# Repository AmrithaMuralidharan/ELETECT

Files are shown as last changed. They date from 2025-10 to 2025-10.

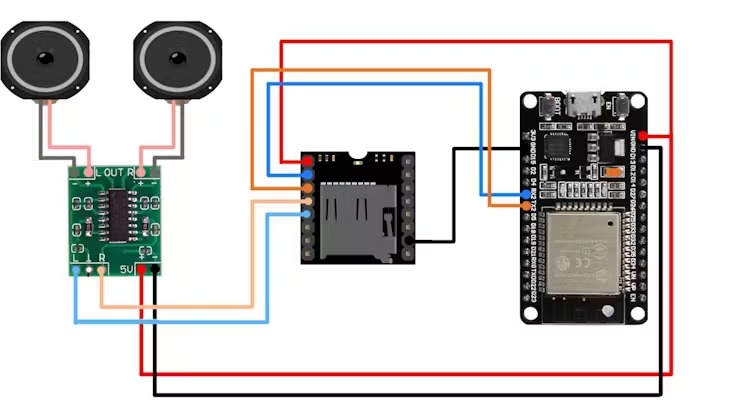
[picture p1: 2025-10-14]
ELETECT 2.O/ELETECT RAZOR/SCHEMATICS AND PCB/eletect.jpg

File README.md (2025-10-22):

# 🐘 EleTect 2.0 – Intelligent Ecosystem for Human–Wildlife Coexistence


[]()
[]()

---

### 🌍 Overview

*EleTect* is a modular, AI-powered ecosystem of devices designed to promote *human–wildlife coexistence*, prevent conflicts, and protect both nature and communities.  
Built using *TinyML, **LoRa, and **bio-inspired design principles, EleTect redefines conservation technology through **low-power, scalable, and sustainable innovation*.

This repository covers the complete *EleTect 2.0 system* and its modular extensions — forming a connected network of intelligent devices that monitor, detect, deter, and communicate in real-time.

---

Field Survey, Official Approval & Real-World Trials
To ensure EleTect was not just a lab prototype but a real-world conservation tool, our team carried out an extensive ground survey and obtained official permission for field testing from the Divisional Forest Officer (DFO) of Kothamangalam, Mr. Varun Dalia, IFS, and Forest Range Officer, Mr. Jaleel.


After the survey phase, we formally presented EleTect to the DFO Office, Kothamangalam, and Forest Range Office to discuss its technical operation, safety, and ecological compatibility.



I’ve started a discussion on WILDLABS for EleTect 2.0: AI-Powered Ecosystem for Human–Wildlife Coexistence — you can check it out here:
🔗 WILDLABS Discussion – https://wildlabs.net/discussion/eletect-20-ai-powered-ecosystem-human-wildlife-coexistence

eletect abhi

Please feel free to drop your insights, suggestions, or deployment experiences — especially if you’ve worked in conservation tech, forest environments, LoRa mesh networks, or wildlife deterrents. I’d love to learn from your field knowledge and improve EleTect’s design, robustness, and real-world usability together with the community.

## 🧩 Ecosystem Lineup

### *1️⃣ EleTect 2.0 – The Core System*
> The central AI-powered unit for *human–elephant conflict mitigation*.

- Dual *vision + acoustic AI* detection for real-time elephant identification.  
- *Bio-inspired deterrent* using honeybee swarm sounds.  
- Detects *illegal human activities* (gunshots, chainsaws, vehicles).  
- *Solar-powered, **LoRa-enabled, and capable of **local data logging* (SD + RTC).  
- Acts as the *hub* of the entire EleTect ecosystem.  

📘 Detailed Documentation: [EleTect 2.0 Hackster Project](https://www.hackster.io/abhinav123krish/eletect-2-0-76abc2)

---

### *2️⃣ EleTect Razor – Modular Boar Deterrent*
> A plug-and-play module that attaches to EleTect 2.0.

- High-intensity *strobe lights* and *ultrasonic deterrence*.  
- EEPROM-based auto-recognition for instant configuration.  
- Designed to adapt EleTect 2.0 for wild boar management.  

---

### *3️⃣ EleTect 1.5 – Smarter Roads, Safer Journeys*
> Intelligent wildlife signage for road safety near forest areas.

- Deployed along *elephant corridors (Aana Thaara)* using local knowledge for placement.  
- Communicates with detection nodes via *LoRa*.  
- *Solar-powered* system that warns vehicles in real-time.  
- Can be extended to detect *other large animals* in crossings.  

📘 Detailed Documentation: [EleTect 1.5 Hackster Project](https://www.hackster.io/abhinav123krish/eletect-1-5-smarter-warnings-safer-journeys-1597d3)

---

### *4️⃣ EleTect Mini – Compact Multi-Animal Deterrent*
> A lightweight, portable solution for farms and households.

- Built using *XIAO ESP32S3 + TinyML*.  
- *Rotary mode selector* for species-specific deterrence (birds, dogs, monkeys, squirrels, etc.).  
- Dual charging: *USB Type-C + Solar*.  
- Features dual “eye” strobes and an intelligent speaker for deterrence.  

---

### *5️⃣ EleTect Echo – Acoustic Surveillance Node*
> The forest’s “ears” — monitoring illegal activity 24/7.

- Detects *gunshots, logging, vehicle movement*, and unusual sounds.  
- Logs acoustic data to SD with timestamps (RTC-based).  
- Transmits alerts via *LoRa MeshStatic* to ranger units.  

---

### *6️⃣ EleTect Ember – Early Wildfire Detection*
> A stackable add-on for Echo, creating a complete forest monitoring suite.

- Detects *smoke, flame, temperature, and **gas anomalies*.  
- Early fire alerts sent to connected *Echo nodes* and *EleTect Link*.  
- Modular “Lego-style” design — Echo and Ember interlock seamlessly.  

---

### *7️⃣ EleTect Link – Ranger Communication Device*
> Handheld, smart, and always connected.

- Connects to EleTect 2.0, Echo, and Ember via *LoRa MeshStatic*.  
- Displays real-time alerts on an *OLED/e-paper screen*.  
- Supports *SOS signaling, **vibration, and **buzzer alerts*.  
- Works fully *offline*, enabling communication deep inside forests.  

---

## 🧠 Innovation Highlights

- ✅ *TinyML + IoT Fusion* – Real-time detection on low-power devices.  
- 🌿 *Bio-inspired Design* – Honeybee deterrence derived from natural elephant behavior.  
- ☀ *Solar-Powered Systems* – Fully off-grid and sustainable.  
- 🔗 *Modular Architecture* – Attach, adapt, and scale easily.  
- 🛰 *LoRa + Mesh Communication* – Long-range, internet-independent alerts.  
- 🧩 *Cross-Compatible Modules* – All devices interconnect as a unified network.  

---

### 🔗 Refer to the Projects documentation on huckster.io
- 🐘 *EleTect 1.0 – Original Prototype:* [Mitigating Human–Elephant Conflict with TinyML](https://www.hackster.io/517317/eletect-mitigating-human-elephant-conflict-with-tinyml-31a66d)  
- 🚦 *EleTect 1.5 – Smarter Warnings, Safer Journeys:* [Smart Wildlife Signage](https://www.hackster.io/abhinav123krish/eletect-1-5-smarter-warnings-safer-journeys-1597d3)  
- 🧠 *EleTect 2.0 – Advanced Ecosystem:* [AI + IoT for Conservation](https://www.hackster.io/abhinav123krish/eletect-2-0-76abc2)

---

## 🚀 Getting Started

### *1️⃣ Clone this repository*
```bash
git clone https://github.com/abhinavkrish/EleTect-2.0.git
cd EleTect-2.0

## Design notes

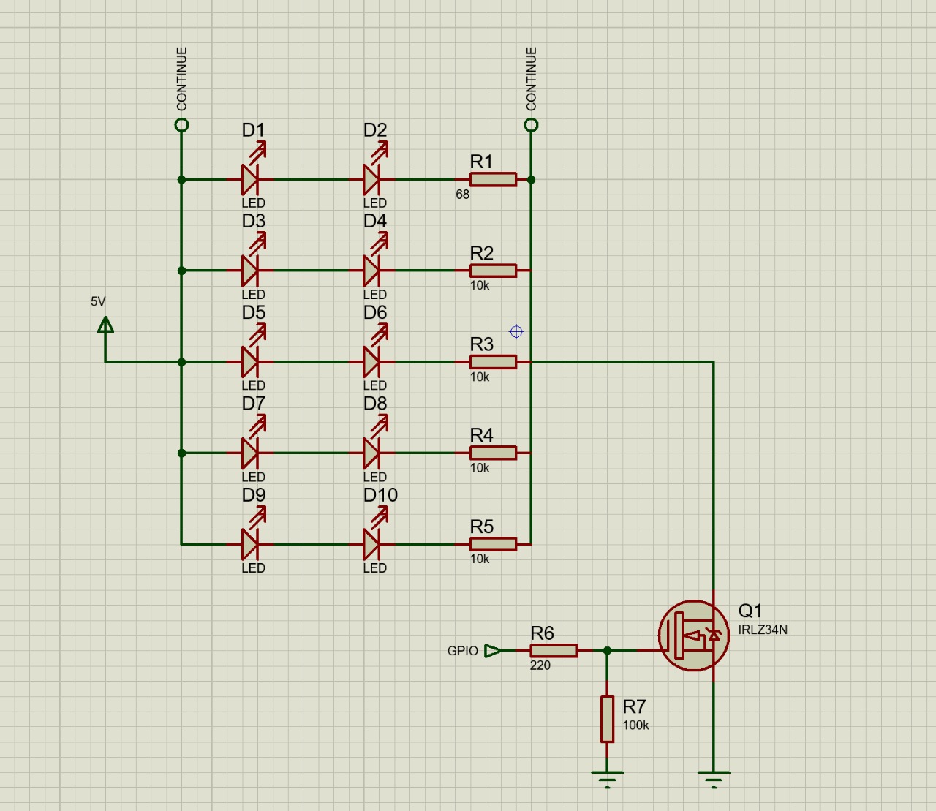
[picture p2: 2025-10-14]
ELETECT 2.O/ELETECT RAZOR/SCHEMATICS AND PCB/eletect (2).jpg

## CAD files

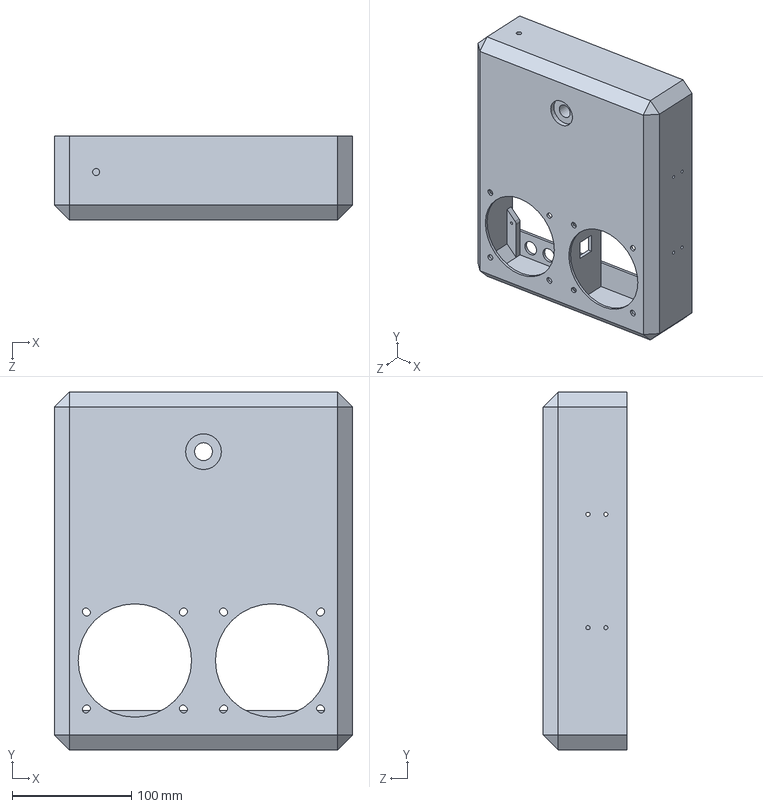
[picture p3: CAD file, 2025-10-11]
ELETECT 2.O/ELETECT 2.O/CAD/Eletect/Main Casing.SLDPRT
250.0 x 300.0 x 70.0 mm

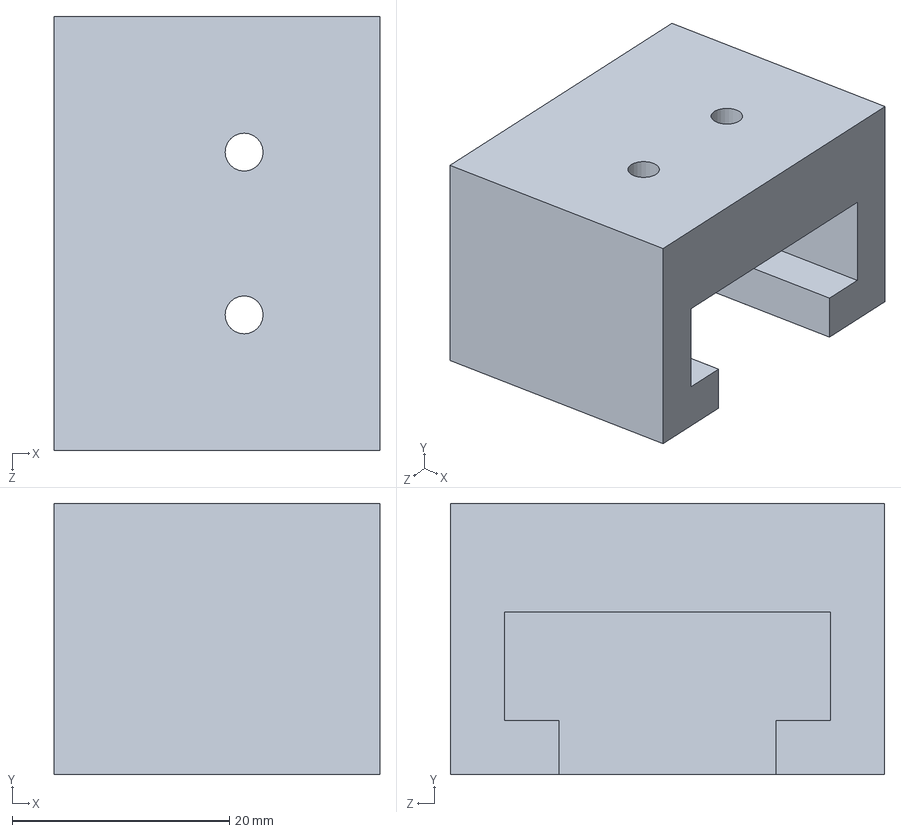
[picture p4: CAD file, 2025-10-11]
ELETECT 2.O/ELETECT 2.O/CAD/Eletect/UCM2.SLDPRT
30.0 x 25.0 x 40.0 mm

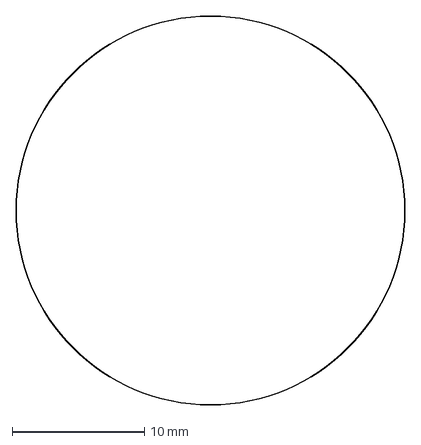
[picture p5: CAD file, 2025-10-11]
ELETECT 2.O/ELETECT 2.O/CAD/Sketch1 .dxf
29.4 x 29.4 mm

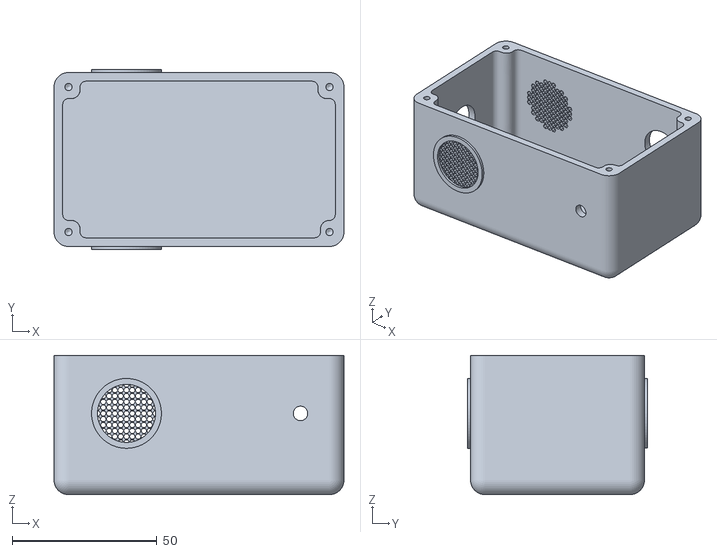
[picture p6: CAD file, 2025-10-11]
ELETECT 2.O/ELETECT ECHO/CAD/BOX1NEW_ v1.stl
100.0 x 62.0 x 48.0

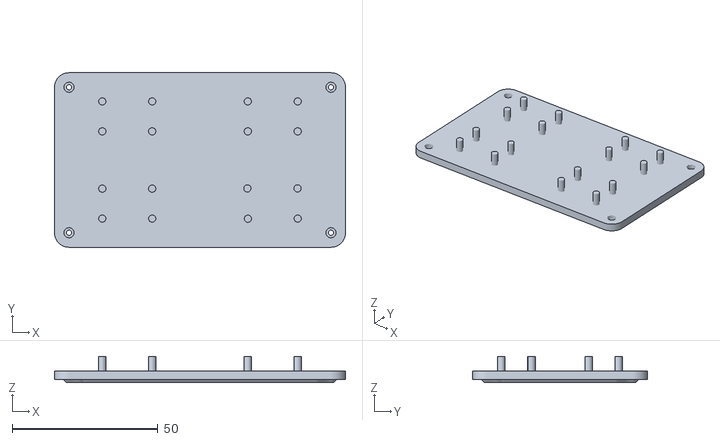
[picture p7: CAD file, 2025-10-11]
ELETECT 2.O/ELETECT EMBER/CAD/lid2NEW_.stl
100.0 x 60.0 x 9.00

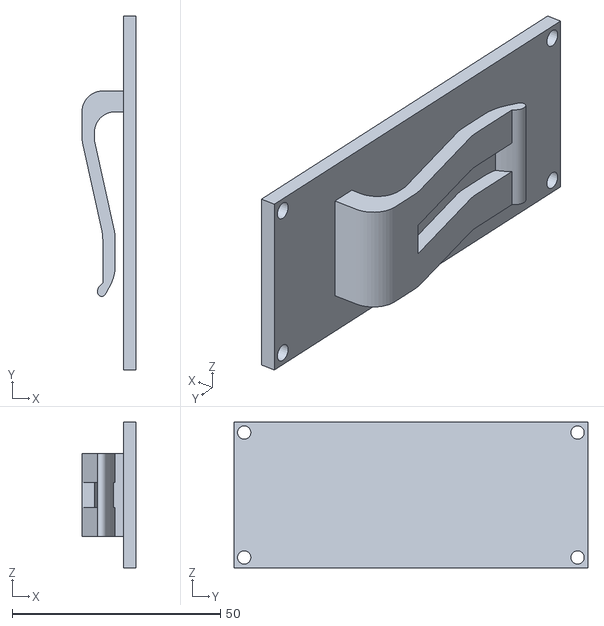
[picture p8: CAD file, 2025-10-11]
ELETECT 2.O/ELETECT LINK/CAD/rangerbp.stl
13.0 x 85.0 x 35.0

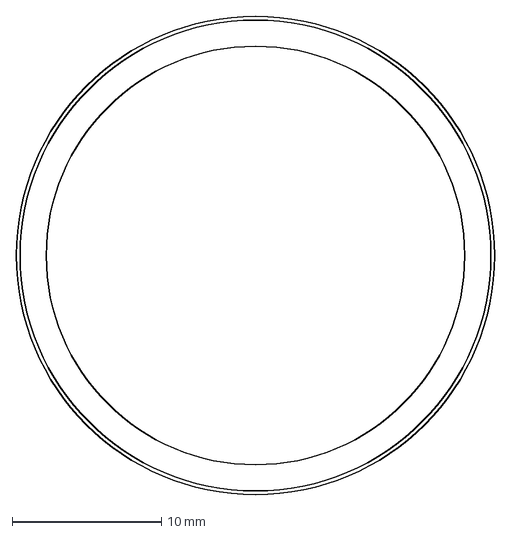
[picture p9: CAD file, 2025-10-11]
ELETECT 2.O/ELETECT MINI/CAD/Sketch2.dxf
32.0 x 32.0 mm

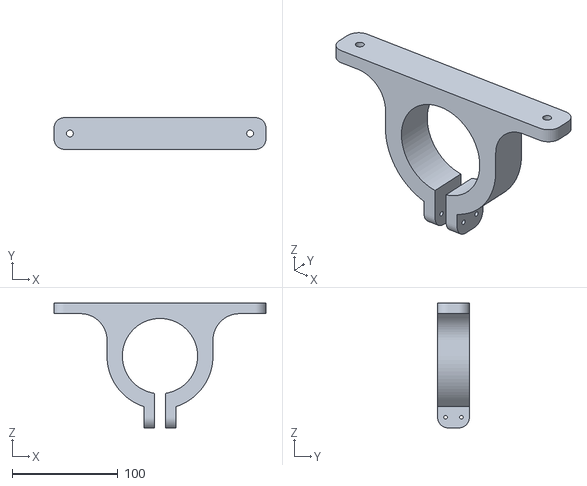
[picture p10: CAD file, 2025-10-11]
ELETECT 2.O/ELETECT RAZOR/CAD/clamping.stl
200.0 x 30.0 x 117.8

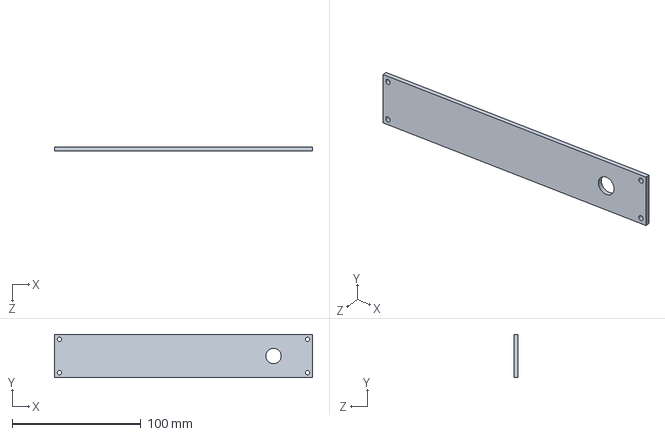
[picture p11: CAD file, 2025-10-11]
ELETECT 2.O/ELETECT RAZOR/CAD/Eletect/us bp.SLDPRT
200.6 x 33.6 x 3.00 mm

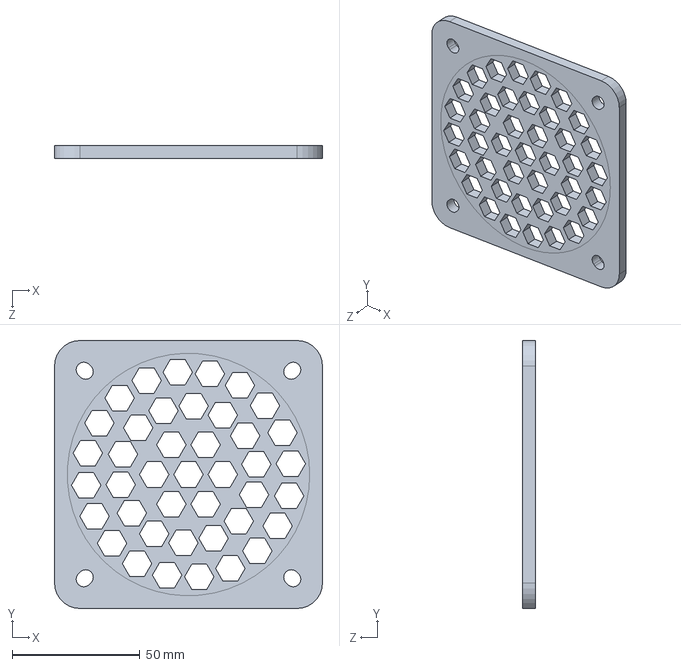
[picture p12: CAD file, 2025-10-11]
ELETECT 2.O/ELETECT 2.O/CAD/Eletect/speaker grill.SLDPRT
105.0 x 105.0 x 5.00 mm

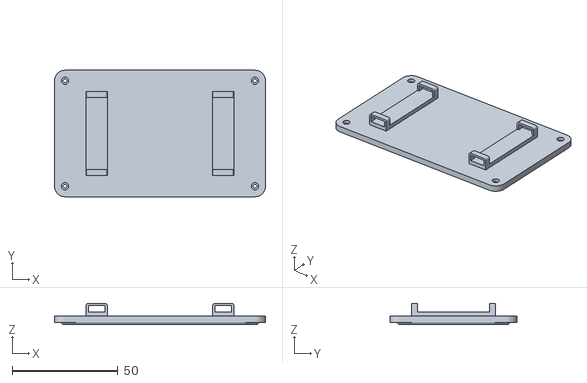
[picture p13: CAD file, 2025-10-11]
ELETECT 2.O/ELETECT ECHO/CAD/lid.stl
100.0 x 60.0 x 10.0

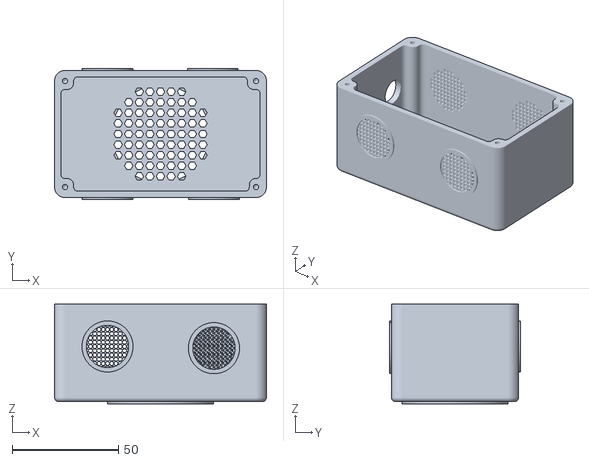
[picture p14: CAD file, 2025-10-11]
ELETECT 2.O/ELETECT EMBER/CAD/box2NEW_ v1.stl
100.0 x 62.0 x 47.1

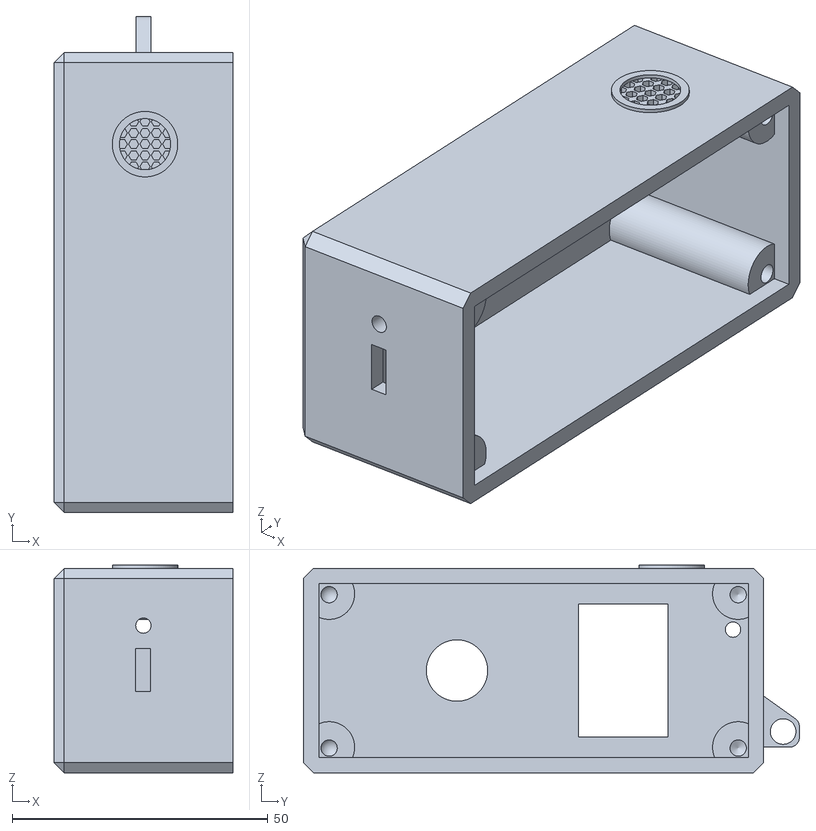
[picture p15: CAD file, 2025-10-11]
ELETECT 2.O/ELETECT LINK/CAD/ranger1.stl
35.0 x 97.0 x 40.6

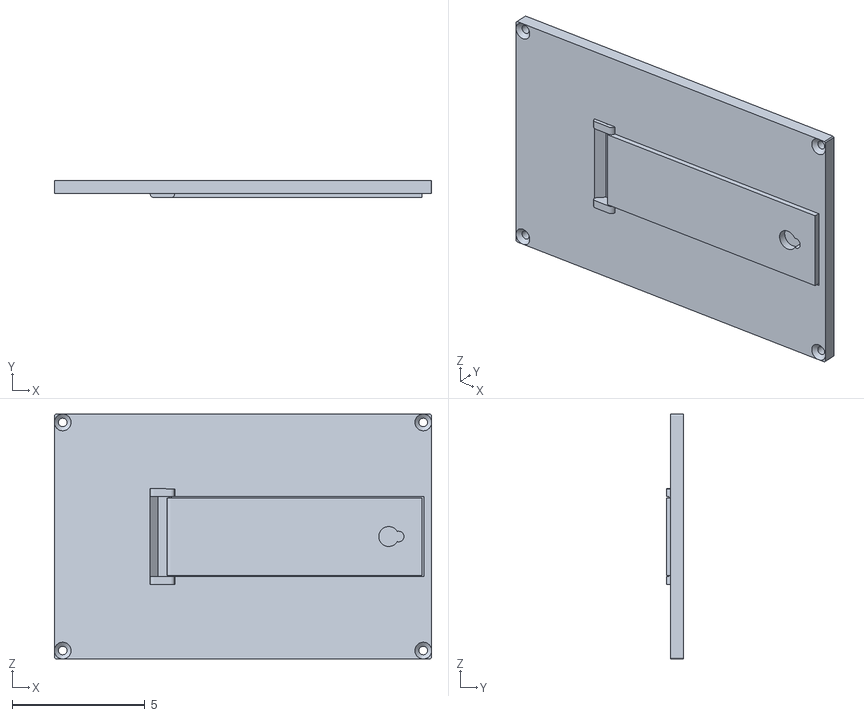
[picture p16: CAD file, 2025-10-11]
ELETECT 2.O/ELETECT MINI/CAD/mini bp.stl
14.2 x 0.65 x 9.22

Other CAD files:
ELETECT 2.O/ELETECT 2.O/CAD/Eletect/Eletect.SLDASM
ELETECT 2.O/ELETECT RAZOR/CAD/Eletect/Eletect.SLDASM
ELETECT 2.O/ELETECT 2.O/CAD/Eletect/1.SLDPRT
ELETECT 2.O/ELETECT 2.O/CAD/Eletect/AC.SLDPRT
ELETECT 2.O/ELETECT 2.O/CAD/Eletect/AL.SLDPRT
ELETECT 2.O/ELETECT 2.O/CAD/Eletect/Back Panel.SLDPRT
ELETECT 2.O/ELETECT 2.O/CAD/Eletect/LM1.SLDPRT
ELETECT 2.O/ELETECT 2.O/CAD/Eletect/LM2.SLDPRT
ELETECT 2.O/ELETECT 2.O/CAD/Eletect/Light casing.SLDPRT
ELETECT 2.O/ELETECT 2.O/CAD/Eletect/UCM1.SLDPRT
ELETECT 2.O/ELETECT 2.O/CAD/Eletect/USC.SLDPRT
ELETECT 2.O/ELETECT 2.O/CAD/Eletect/clamping.SLDPRT
ELETECT 2.O/ELETECT 2.O/CAD/Eletect/light back panel.SLDPRT
ELETECT 2.O/ELETECT 2.O/CAD/Sketch1.dxf
ELETECT 2.O/ELETECT MINI/CAD/Sketch3.dxf
ELETECT 2.O/ELETECT MINI/CAD/mini case.stl
ELETECT 2.O/ELETECT RAZOR/CAD/Eletect/1.SLDPRT
ELETECT 2.O/ELETECT RAZOR/CAD/Eletect/AC.SLDPRT
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

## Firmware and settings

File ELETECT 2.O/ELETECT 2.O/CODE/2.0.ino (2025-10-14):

/*  final version
   - Grove Vision AI V2 (UART)
   - Edge Impulse audio inference (XIAO ESP32S3)
   - DFRobotDFPlayerMini playback (random files: /01 honeybee, /02 boar)
   - SD logging: /log.csv (detailed) and /events.csv (timestamp,event,locality)
   - RTC DS3231 for timestamps
   - Meshtastic UART (Serial2) send
   - EEPROM probe at 0x50 -> if present, switch to BOAR mode (razor add-on attached)
   - BOAR deterrent: randomized strobes + ultrasonic PWM
*/

/* === LIBRARIES === */
#include <Wire.h>
#include <SPI.h>
#include <SD.h>
#include <LoRa.h>
#include <RTClib.h>

#include <Seeed_Arduino_SSCMA.h>     // Grove Vision AI V2 (UART API)
#include "DFRobotDFPlayerMini.h"    // DFPlayer library
#include <SoftwareSerial.h>

#define EIDSP_QUANTIZE_FILTERBANK   0
#include <EleTect_inferencing.h>    // Edge Impulse inferencing glue
#include <I2S.h>

/* === HARDWARE / PIN CONFIG - EDIT THESE TO MATCH YOUR WIRING === */

// DFPlayer SoftwareSerial pins (example)
#define DFPLAYER_SOFT_RX 10 // connect to DFPlayer TX
#define DFPLAYER_SOFT_TX 11 // connect to DFPlayer RX

// SD card for logging
#define SD_CS_PIN 5       // change to match wiring

// LoRa pins (example)
#define LORA_SS    18
#define LORA_RST   14
#define LORA_DIO0  26
#define LORA_FREQ  915E6  // change to your region: 433E6 / 868E6 / 915E6

// I2S pins for audio capture (change if your mic uses different pins)
#define I2S_BCK_PIN  -1
#define I2S_WS_PIN   42
#define I2S_DIN_PIN  41
#define I2S_DOUT_PIN -1

// Meshtastic UART pins (change to your wiring)
const int MESHTASTIC_RX_PIN = 16; // XIAO RX (connect to Wio TX)
const int MESHTASTIC_TX_PIN = 17; // XIAO TX (connect to Wio RX)
const unsigned long MESHTASTIC_BAUD = 38400; // must match Serial Module baud

/* === BOAR-DETERRER / EEPROM ADD-ON PINS & SETTINGS ===
   NOTE: change pins below if they conflict with your wiring.
   I chose default pins that minimize collision with the other defaults above.
*/
#define EEPROM_I2C_ADDR 0x50   // typical 24LC02 address
#define EEPROM_CHECK_INTERVAL 5000UL // ms: re-check EEPROM presence

// Strobe/ultrasonic pins - change if these collide with other devices
const int STROBE1_PIN = 32;   // MOSFET gate for strobe 1
const int STROBE2_PIN = 33;   // MOSFET gate for strobe 2
const int ULTRA_PIN   = 25;   // PWM pin for ultrasonic tweeter

// ultrasonic PWM settings (ledc)
const int ULTRA_FREQ = 25000; // 25 kHz (tweak for your tweeter)
const int ULTRA_CHANNEL = 1;  // ledc channel (use a free channel)
const int ULTRA_RESOLUTION = 8; // 8-bit duty (0..255)
const int ULTRA_MAX_DUTY = 200; // maximum duty (tune to hardware)

// deterrent timing & randomness
const unsigned long BOAR_DETERR_COOLDOWN_MS = 15000UL;   // cooldown between deterrent triggers
const unsigned long DETERR_MIN_MS = 5000UL;  // min duration of deterrent (ms)
const unsigned long DETERR_MAX_MS = 12000UL; // max duration of deterrent (ms)

/* === GENERAL DEFINITIONS / FILES === */
#define LOG_CSV    "/log.csv"
#define EVENTS_CSV "/events.csv"

#ifdef ESP32
  #include <HardwareSerial.h>
  HardwareSerial atSerial(0); // Grove Vision UART (keeps your original approach)
#else
  #define atSerial Serial1
#endif

SSCMA AI;                         // Vision AI object
SoftwareSerial mySoftSerial(DFPLAYER_SOFT_RX, DFPLAYER_SOFT_TX);
DFRobotDFPlayerMini myDFPlayer;

RTC_DS3231 rtc;
File logFile;

/* DFPlayer folders / defaults */
const uint8_t ELEPHANT_FOLDER = 1; // honeybee sounds in /01/
const uint8_t BOAR_FOLDER      = 2; // crackers/predator in /02/
const uint8_t NUM_FILES_PER_FOLDER = 20; // fallback

const int SCORE_THRESHOLD = 80;   // vision score threshold (0..100)
const unsigned long PLAYBACK_COOLDOWN_MS = 10000UL; // cool-down for audio/vision playback
unsigned long lastElephantAt = 0;
unsigned long lastBoarAt     = 0;

/* EDGE IMPULSE AUDIO BUFFERS (adapted) */
typedef struct {
    int16_t *buffer;
    uint8_t buf_ready;
    uint32_t buf_count;
    uint32_t n_samples;
} inference_t;

static inference_t inference;
static const uint32_t sample_buffer_size = 2048;
static signed short sampleBuffer[sample_buffer_size];
static bool debug_nn = false;
static bool record_status = true;

const float CONFIDENCE_THRESHOLD = 0.60f; // audio classification threshold

/* STATE FLAGS */
bool sd_ok = false;
bool rtc_ok = false;
bool meshtastic_ok = false;
bool eepromPresent = false;
unsigned long lastEEPROMCheck = 0;
unsigned long lastBoarDeterrentAt = 0;

/* FORWARD DECLARATIONS */
String detectVision();
String detectAudio();
void playRandomFromFolder(uint8_t folderNumber);
void logEvent(DateTime ts, const String &visionLabel, const String &audioLabel, const String &action, const String &soundFile, const String &loraStatus);
bool sendLoRa(const String &visionLabel, const String &audioLabel, const String &action);
String timestampNow();
void appendEvent(const String &timestamp, const String &event);
void meshtastic_begin();
void sendMeshtastic(const char *eventName);

/* BOAR deterrent helpers */
bool probeEEPROM();                 // probe I2C EEPROM presence
void updateModeFromEEPROM();        // set mode based on probe
void runBoarDeterrent();            // start randomized deterrent
void runStrobePattern(int onMs, int offMs, int repeats, bool alternate);
void runRandomSingleStrobe(int count, int minMs, int maxMs);

/* === AUDIO CAPTURE HELPERS (Edge Impulse) === */
static void audio_inference_callback(uint32_t n_bytes)
{
    for(int i = 0; i < (n_bytes >> 1); i++) {
        inference.buffer[inference.buf_count++] = sampleBuffer[i];
        if(inference.buf_count >= inference.n_samples) {
            inference.buf_count = 0;
            inference.buf_ready = 1;
        }
    }
}

static void capture_samples(void* arg) {
  const int32_t i2s_bytes_to_read = (uint32_t)arg;
  size_t bytes_read = i2s_bytes_to_read;
  while (record_status) {
    esp_i2s::i2s_read(esp_i2s::I2S_NUM_0, (void*)sampleBuffer, i2s_bytes_to_read, &bytes_read, 100);
    if (bytes_read <= 0) {
      ei_printf("Error in I2S read : %d", bytes_read);
    } else {
      if (bytes_read < i2s_bytes_to_read) {
        ei_printf("Partial I2S read");
      }
      for (int x = 0; x < i2s_bytes_to_read/2; x++) {
        sampleBuffer[x] = (int16_t)(sampleBuffer[x]) * 8;
      }
      if (record_status) {
        audio_inference_callback(i2s_bytes_to_read);
      } else {
        break;
      }
    }
  }
  vTaskDelete(NULL);
}

static bool microphone_inference_start(uint32_t n_samples)
{
    inference.buffer = (int16_t *)malloc(n_samples * sizeof(int16_t));
    if(inference.buffer == NULL) {
        return false;
    }
    inference.buf_count  = 0;
    inference.n_samples  = n_samples;
    inference.buf_ready  = 0;
    ei_sleep(100);
    record_status = true;
    xTaskCreate(capture_samples, "CaptureSamples", 1024 * 32, (void*)sample_buffer_size, 10, NULL);
    return true;
}

static bool microphone_inference_record(void)
{
    while (inference.buf_ready == 0) {
        delay(10);
    }
    inference.buf_ready = 0;
    return true;
}

static int microphone_audio_signal_get_data(size_t offset, size_t length, float *out_ptr)
{
    numpy::int16_to_float(&inference.buffer[offset], out_ptr, length);
    return 0;
}

static void microphone_inference_end(void)
{
    if (inference.buffer) {
        ei_free(inference.buffer);
        inference.buffer = NULL;
    }
}

/* === VISION (UART-based) === */
String detectVision() {
  if (!AI.invoke(1, false, false)) {
    auto &boxes = AI.boxes();
    for (int i = 0; i < boxes.size(); i++) {
      int score = boxes[i].score;
      if (score > SCORE_THRESHOLD) {
        String label = boxes[i].label;
        label.toLowerCase();
        label.trim();
        if (label == "elephant" || label.indexOf("eleph") >= 0) {
          Serial.printf("{ \"elephant_detected\": %d }\n", score);
          return "elephant";
        } else if (label == "boar" || label == "wildboar" || label.indexOf("boar") >= 0) {
          Serial.printf("{ \"boar_detected\": %d }\n", score);
          return "wildboar";
        } else {
          Serial.printf("{ \"%s_detected\": %d }\n", label.c_str(), score);
          return label;
        }
      }
    }
  }
  return "none";
}

/* === AUDIO DETECTION WRAPPER === */
String detectAudio() {
  if (!microphone_inference_record()) {
    ei_printf("ERR: Failed to record audio...\n");
    return "none";
  }
  signal_t signal;
  signal.total_length = EI_CLASSIFIER_RAW_SAMPLE_COUNT;
  signal.get_data = &microphone_audio_signal_get_data;
  ei_impulse_result_t result = { 0 };
  EI_IMPULSE_ERROR r = run_classifier(&signal, &result, debug_nn);
  if (r != EI_IMPULSE_OK) {
    ei_printf("ERR: Failed to run classifier (%d)\n", r);
    return "none";
  }
  int pred_index = -1;
  float pred_value = 0.0f;
  for (size_t ix = 0; ix < EI_CLASSIFIER_LABEL_COUNT; ix++) {
    if (result.classification[ix].value > pred_value) {
      pred_index = ix;
      pred_value = result.classification[ix].value;
    }
  }
  if (pred_index < 0 || pred_value < CONFIDENCE_THRESHOLD) {
    ei_printf("No confident detection (best: %d = %f)\n", pred_index, pred_value);
    return "none";
  }
  const char *label = result.classification[pred_index].label;
  ei_printf("DETECTED (audio): %s (%.2f)\n", label, pred_value);
  return String(label);
}

/* === DFPlayer helper === */
void playRandomFromFolder(uint8_t folderNumber) {
  int fileCount = myDFPlayer.readFileCountsInFolder(folderNumber);
  if (fileCount <= 0) fileCount = NUM_FILES_PER_FOLDER;
  int fileIndex = random(1, fileCount + 1);
  int vol = 28 + (random(0, 3)); // 28-30
  if (vol > 30) vol = 30;
  myDFPlayer.volume(vol);
  Serial.print("Playing folder ");
  Serial.print(folderNumber);
  Serial.print(" file ");
  Serial.print(fileIndex);
  Serial.print(" at volume ");
  Serial.println(vol);
  myDFPlayer.playFolder(folderNumber, fileIndex);
}

/* === DETAILED LOGGING === */
void logEvent(DateTime ts, const String &visionLabel, const String &audioLabel, const String &action, const String &soundFile, const String &loraStatus) {
  if (!sd_ok) {
    Serial.println("SD not available, skipping detailed log");
    return;
  }
  File f = SD.open(LOG_CSV, FILE_APPEND);
  if (!f) {
    Serial.println("Failed to open " LOG_CSV);
    return;
  }
  char timestr[32];
  snprintf(timestr, sizeof(timestr), "%04d-%02d-%02d %02d:%02d:%02d",
           ts.year(), ts.month(), ts.day(), ts.hour(), ts.minute(), ts.second());
  String line = String(timestr) + "," + visionLabel + "," + audioLabel + "," + action + "," + soundFile + "," + loraStatus + "\n";
  f.print(line);
  f.close();
  Serial.println("Logged (detailed): " + line);
}

/* === EVENTS CSV (timestamp,event,locality) === */
String timestampNow() {
  if (rtc_ok) {
    DateTime now = rtc.now();
    char buf[32];
    snprintf(buf, sizeof(buf), "%04d-%02d-%02d %02d:%02d:%02d",
             now.year(), now.month(), now.day(),
             now.hour(), now.minute(), now.second());
    return String(buf);
  } else {
    unsigned long s = millis() / 1000;
    char buf[32];
    snprintf(buf, sizeof(buf), "uptime_%lus", s);
    return String(buf);
  }
}

void appendEvent(const String &timestamp, const String &event) {
  if (!sd_ok) {
    Serial.println("SD not available, skipping events.csv append");
    return;
  }
  File f = SD.open(EVENTS_CSV, FILE_WRITE); // append mode
  if (!f) {
    Serial.println("Error opening " EVENTS_CSV " for append");
    return;
  }
  String safeEvent = event;
  safeEvent.replace(",", " ");
  f.print(timestamp);
  f.print(",");
  f.print("\"");
  f.print(safeEvent);
  f.print("\"");
  f.print(",");
  f.println("kothamangalam");
  f.close();
  Serial.print("Logged (event): ");
  Serial.print(timestamp);
  Serial.print(" , ");
  Serial.println(safeEvent);
}

/* === LoRa send === */
bool sendLoRa(const String &visionLabel, const String &audioLabel, const String &action) {
  String payload = String("{\"t\":\"") + String(millis()) + String("\",\"v\":\"") + visionLabel + String("\",\"a\":\"") + audioLabel + String("\",\"act\":\"") + action + String("\"}");
  LoRa.beginPacket();
  LoRa.print(payload);
  LoRa.endPacket();
  Serial.println("LoRa sent: " + payload);
  return true;
}

/* === Meshtastic helpers === */
void meshtastic_begin() {
  Serial2.begin(MESHTASTIC_BAUD, SERIAL_8N1, MESHTASTIC_RX_PIN, MESHTASTIC_TX_PIN);
  delay(50);
  meshtastic_ok = true;
  Serial.println("Meshtastic UART (Serial2) initialized.");
}

void sendMeshtastic(const char *eventName) {
  if (!meshtastic_ok) {
    Serial.println("Meshtastic not initialized, skip sending");
    return;
  }
  String ts = timestampNow();
  String payload = String("{\"loc\":\"kothamangalam\",\"time\":\"") + ts + String("\",\"event\":\"") + eventName + String("\"}");
  Serial.print("-> mesh: ");
  Serial.println(payload);
  Serial2.println(payload);
}

/* === EEPROM / BOAR DETERRER === */
bool probeEEPROM() {
  Wire.beginTransmission(EEPROM_I2C_ADDR);
  byte err = Wire.endTransmission();
  if (err == 0) {
    Serial.println("EEPROM detected on I2C (0x50) - razor add-on attached");
    return true;
  } else {
    //Serial.println("No EEPROM detected at 0x50");
    return false;
  }
}
void updateModeFromEEPROM() {
  // If EEPROM present, enable BOAR deterrent mode
  if (eepromPresent) {
    Serial.println("Mode: BOAR (deterrent enabled)");
  } else {
    Serial.println("Mode: ELEPHANT (deterrent disabled)");
  }
}

void runBoarDeterrent() {
  unsigned long now = millis();
  if (now - lastBoarDeterrentAt < BOAR_DETERR_COOLDOWN_MS) {
    Serial.println("Boar deterrent on cooldown — skip");
    return;
  }
  lastBoarDeterrentAt = now;

  unsigned long duration = random((int)DETERR_MIN_MS, (int)DETERR_MAX_MS + 1);
  unsigned long endAt = millis() + duration;
  int ultraDuty = random(150, ULTRA_MAX_DUTY + 1); // 150..MAX

  // Start ultrasonic tone
  ledcWrite(ULTRA_CHANNEL, ultraDuty);
  Serial.print("Ultrasonic ON, duty=");
  Serial.println(ultraDuty);

  // Strobe loop until duration elapsed
  while (millis() < endAt) {
    int pattern = random(0, 4);
    switch (pattern) {
      case 0:
        runStrobePattern(100, 100, 8, true);
        break;
      case 1:
        runStrobePattern(60, 60, 12, false);
        break;
      case 2:
        runRandomSingleStrobe(6, 30, 150);
        break;
      case 3:
        runStrobePattern(250, 150, 6, true);
        break;
    }
    delay(random(80,400));
  }

  // stop ultrasonic
  ledcWrite(ULTRA_CHANNEL, 0);
  Serial.println("Ultrasonic OFF");

  // ensure strobes off
  digitalWrite(STROBE1_PIN, LOW);
  digitalWrite(STROBE2_PIN, LOW);
  Serial.println("Boar deterrent sequence complete");
}

void runStrobePattern(int onMs, int offMs, int repeats, bool alternate) {
  for (int i = 0; i < repeats; ++i) {
    if (alternate) {
      if (i % 2 == 0) {
        digitalWrite(STROBE1_PIN, HIGH);
        digitalWrite(STROBE2_PIN, LOW);
      } else {
        digitalWrite(STROBE1_PIN, LOW);
        digitalWrite(STROBE2_PIN, HIGH);
      }
    } else {
      digitalWrite(STROBE1_PIN, HIGH);
      digitalWrite(STROBE2_PIN, HIGH);
    }
    delay(onMs);
    digitalWrite(STROBE1_PIN, LOW);
    digitalWrite(STROBE2_PIN, LOW);
    delay(offMs);
  }
}

void runRandomSingleStrobe(int count, int minMs, int maxMs) {
  int pin = (random(0, 2) == 0) ? STROBE1_PIN : STROBE2_PIN;
  for (int i = 0; i < count; ++i) {
    digitalWrite(pin, HIGH);
    delay(random(minMs, maxMs));
    digitalWrite(pin, LOW);
    delay(random(minMs, maxMs));
  }
}
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
void loop() {
  // Periodically check EEPROM presence so mode can change at runtime
  if (millis() - lastEEPROMCheck >= EEPROM_CHECK_INTERVAL) {
    bool nowPresent = probeEEPROM();
    if (nowPresent != eepromPresent) {
      eepromPresent = nowPresent;
      updateModeFromEEPROM();
    }
    lastEEPROMCheck = millis();
  }

  DateTime nowDT = rtc_ok ? rtc.now() : DateTime(F(_DATE), F(TIME_));
  String visionLabel = "none";
  String audioLabel  = "none";

  if (millis() - lastVisionMs >= VISION_INTERVAL_MS) {
    lastVisionMs = millis();
    visionLabel = detectVision();
  }

  if (millis() - lastAudioMs >= AUDIO_INTERVAL_MS) {
    lastAudioMs = millis();
    audioLabel = detectAudio(); // blocking while a frame is recorded
  }

  // Decide action and play/act accordingly
  String action = "none";
  String playedFile = "-";

  if (visionLabel.equalsIgnoreCase("elephant") || audioLabel.equalsIgnoreCase("elephant")) {
    if (millis() - lastElephantAt >= PLAYBACK_COOLDOWN_MS) {
      lastElephantAt = millis();
      action = "play_honeybee";
      playRandomFromFolder(ELEPHANT_FOLDER);
      playedFile = String("folder") + String(ELEPHANT_FOLDER);
      appendEvent(timestampNow(), "elephant detected");
    } else {
      Serial.println("Elephant detection but on cooldown (skip playback)");
    }
  } else if (visionLabel.equalsIgnoreCase("wildboar") || audioLabel.equalsIgnoreCase("wildboar") ||
             visionLabel.equalsIgnoreCase("boar") || audioLabel.equalsIgnoreCase("boar")) {
    bool didDeterrent = false;
    if (eepromPresent) {
      // razor add-on present -> BOAR mode: run deterrent (if cooldown passed)
      if (millis() - lastBoarDeterrentAt >= BOAR_DETERR_COOLDOWN_MS) {
        runBoarDeterrent(); // runs strobes + ultrasonic (includes its own cooldown update)
        didDeterrent = true;
        appendEvent(timestampNow(), "boar detected - deterrent run");
      } else {
        Serial.println("Boar detected but deterrent on cooldown; continuing with playback only");
      }
    }

    // Always also do sound playback (unless in your setup you want only deterrent)
    if (millis() - lastBoarAt >= PLAYBACK_COOLDOWN_MS) {
      lastBoarAt = millis();
      action = "play_cracker";
      playRandomFromFolder(BOAR_FOLDER);
      playedFile = String("folder") + String(BOAR_FOLDER);
      if (!didDeterrent) appendEvent(timestampNow(), "boar detected"); // log event if deterrent not run
    } else {
      Serial.println("Boar detection playback cooldown hit (skip playback)");
    }
  } else {
    // other audio detections (gunshot/saw/vehicle) from audioLabel
    if (audioLabel.equalsIgnoreCase("gunshot") || audioLabel.indexOf("gun") >= 0) {
      action = "gunshot_detected";
      appendEvent(timestampNow(), "gun detected");
    } else if (audioLabel.equalsIgnoreCase("saw")) {
      action = "saw_detected";
      appendEvent(timestampNow(), "saw detected");
    } else if (audioLabel.equalsIgnoreCase("vehicle")) {
      action = "vehicle_detected";
      appendEvent(timestampNow(), "vehicle detected");
    }
  }

  // send LoRa + Meshtastic if action happened
  String loraStatus = "none";
  if (action != "none") {
    bool ok = sendLoRa(visionLabel, audioLabel, action);
    loraStatus = ok ? "sent" : "failed";

    if (meshtastic_ok) {
      if (action == "play_honeybee") sendMeshtastic("elephant");
      else if (action == "play_cracker") sendMeshtastic("boar");
      else if (action == "gunshot_detected") sendMeshtastic("gun");
      else if (action == "saw_detected") sendMeshtastic("saw");
      else if (action == "vehicle_detected") sendMeshtastic("vehicle");
      else sendMeshtastic(action.c_str());
    }
  }

  // Detailed logging into /log.csv
  logEvent(nowDT, visionLabel, audioLabel, action, playedFile, loraStatus);

  delay(50);
}

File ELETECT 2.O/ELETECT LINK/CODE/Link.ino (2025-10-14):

/**
  Eletect Link
  - Receives alerts from EleTect2.0, Echo and Ember over Meshtastic Serial Module (Serial2)
  - Displays alerts on SSD1306 OLED (I2C)
  - Activates red LED (MOSFET) + vibration motor on alert
  - SOS push-button sends {"sos":"<USERNAME>","loc":"<LOCATION>","t":<uptime_sec>} via Meshtastic
  - Non-blocking timers and debounced button
*/

/* === CONFIG - edit to suit your wiring & preferences === */

// Meshtastic UART (Serial2)
const int MESHTASTIC_RX_PIN = 16; // XIAO RX (connect to Wio TX)
const int MESHTASTIC_TX_PIN = 17; // XIAO TX (connect to Wio RX)
const unsigned long MESHTASTIC_BAUD = 38400UL;

// OLED (I2C) - use default SDA/SCL pins for XIAO
#include <Wire.h>
#include <Adafruit_GFX.h>
#include <Adafruit_SSD1306.h>
#define SCREEN_WIDTH 128
#define SCREEN_HEIGHT 64
#define OLED_RESET    -1
Adafruit_SSD1306 display(SCREEN_WIDTH, SCREEN_HEIGHT, &Wire, OLED_RESET);

// Visual / Haptic outputs (MOSFET-driven)
const int SIGN_LED_PIN = 25;    // Red LED via MOSFET gate
const int VIBE_PIN = 26;        // Vibration motor driver (MOSFET)

// SOS push-button
const int SOS_BTN_PIN = 27;     // digital input with pullup
const unsigned long SOS_DEBOUNCE_MS = 50;
const unsigned long SOS_PRESS_COOLDOWN_MS = 5000; // don't resend SOS more than once per 5s

// Alert behaviour
const unsigned long ALERT_DURATION_MS = 15000UL;   // how long we vibrate+blink on each alert
const unsigned long LED_BLINK_ON_MS  = 300UL;
const unsigned long LED_BLINK_OFF_MS = 300UL;

// UI / history
const int ALERT_HISTORY_MAX = 6;

// User identity / location to send with SOS
const char *USER_NAME = "Ranger_Anil";
const char *LOCATION = "10.1234,76.1234";  // lat,lon — replace with your coordinates or GPS later

/* === Libraries === */
#include <ArduinoJson.h>

/* === State & structures === */

struct Alert {
  String atype;   // e.g., "elephant", "poaching", "tree_cutting", "vehicle", "wildfire", "unknown"
  String src;     // source: "audio","ember","vision", etc.
  String details; // message text or JSON excerpt
  unsigned long time_ms; // millis() when received
};

Alert alertHistory[ALERT_HISTORY_MAX];
int alertHistoryCount = 0;

// Active alert state (last incoming alert triggers this)
bool alertActive = false;
unsigned long alertActivatedAt = 0;

// LED blink state machine
bool ledStateOn = false;
unsigned long ledStateChangeAt = 0;

// Vibration state - we just turn on for ALERT_DURATION_MS but could blink
bool vibeOn = false;

// Meshtastic Serial buffer
String incomingBuf = "";

// SOS button state
unsigned long lastBtnChangeAt = 0;
bool lastBtnState = HIGH;
unsigned long lastSOSSentAt = 0;

// Meshtastic serial object uses Serial2 (hardware)
HardwareSerial &meshSerial = Serial2;

/* === Helper functions === */

void pushAlert(const Alert &a) {
  // keep history as FIFO
  if (alertHistoryCount < ALERT_HISTORY_MAX) {
    alertHistory[alertHistoryCount++] = a;
  } else {
    // shift left and append
    for (int i = 1; i < ALERT_HISTORY_MAX; ++i) alertHistory[i-1] = alertHistory[i];
    alertHistory[ALERT_HISTORY_MAX-1] = a;
  }
}

void triggerAlert(const Alert &a) {
  Serial.print("Trigger alert: "); Serial.println(a.atype);
  pushAlert(a);
  alertActive = true;
  alertActivatedAt = millis();
  // start LED/vibe
  ledStateOn = true;
  digitalWrite(SIGN_LED_PIN, HIGH);
  ledStateChangeAt = millis();
  digitalWrite(VIBE_PIN, HIGH);
  vibeOn = true;
  // update display immediately
  drawActiveAlert(a);
}

/* Draw functions */
void drawActiveAlert(const Alert &a) {
  display.clearDisplay();
  display.setTextSize(1);
  display.setTextColor(SSD1306_WHITE);
  display.setCursor(0,0);
  display.setTextSize(2);
  display.println(a.atype); // big
  display.setTextSize(1);
  display.print("src: ");
  display.println(a.src);
  display.print("t: ");
  unsigned long sec = a.time_ms / 1000UL;
  display.println(sec);
  display.println();
  display.println(a.details);
  display.display();
}

void drawHistoryScreen() {
  display.clearDisplay();
  display.setTextSize(1);
  display.setTextColor(SSD1306_WHITE);
  display.setCursor(0,0);
  display.println("Eletect Link - Alerts");
  display.println("---------------------");
  int start = max(0, alertHistoryCount - 4);
  for (int i = start; i < alertHistoryCount; ++i) {
    unsigned long sec = alertHistory[i].time_ms / 1000UL;
    // show "[t] type src"
    String line = String("[") + String(sec) + String("s] ") + alertHistory[i].atype + String(" ") + alertHistory[i].src;
    if (line.length() > 27) line = line.substring(0, 27);
    display.println(line);
  }
  display.display();
}

/* Send SOS function */
void sendSOS() {
  unsigned long now = millis();
  if (now - lastSOSSentAt < SOS_PRESS_COOLDOWN_MS) {
    Serial.println("SOS suppressed due to cooldown");
    return;
  }
  lastSOSSentAt = now;

  // Create JSON: {"sos":"<user>","loc":"<lat,lon>","t":<uptime_s>}
  StaticJsonDocument<256> doc;
  doc["sos"] = USER_NAME;
  doc["loc"] = LOCATION;
  doc["t"] = now / 1000UL;
  char buf[256];
  size_t n = serializeJson(doc, buf);
  // send via Meshtastic Serial2 (TEXTMSG)
  meshSerial.println(buf);
  Serial.print("Sent SOS: "); Serial.println(buf);

  // immediate feedback
  // short vibration + LED blink
  digitalWrite(VIBE_PIN, HIGH);
  digitalWrite(SIGN_LED_PIN, HIGH);
  delay(300);
  digitalWrite(VIBE_PIN, LOW);
  digitalWrite(SIGN_LED_PIN, LOW);
}
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
